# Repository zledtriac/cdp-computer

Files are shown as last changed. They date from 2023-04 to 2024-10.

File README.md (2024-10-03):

# CDP computer
<div align="center">
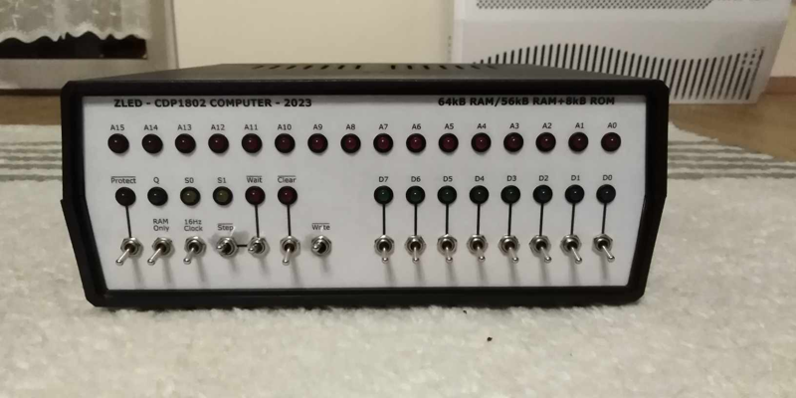
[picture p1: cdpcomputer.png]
  
</div>
This computer is based on the CDP1802 CPU, made for practicing and learning 
electronics and programming. The computer is similar to the COSMAC ELF but I 
designed it from scratch. I tried to fully utilize the features of the CPU and 
I hope I was able to implement enough stuff to demonstrate how an old computer
worked back then.

The fully assembled computer has a frontpanel with switches and two row of LEDs.
The first top row indicates the memory address, and then the next row indicates
the data and the control signals. The switches can be used to input data
in the memory and to control the CPU.

## The motherboard
I made the motherboard to be able to run by itself, so for someone who just want
to do some experiments with an old hardware, it is not necessary to build the 
whole computer. The motherboard contains the CPU, RAM, ROM and the clock 
generator.

### The clock generator
The clock runs on 2.4576MHz so if someone want to make a software Serial 
communcation with the Q and EF pins, 9600 baudrate can be achieved with high 
accuracy.

### The memory
The memory is divided into two sections ROM and RAM, but there is an option to
use only RAM for the program too. This is because EPROMs is a bit difficult to
obtain so for those who are just experimenting, the ROM is not necessary to
make the motherboard running, the RAM is enough. If the J5 pins are shorted the
motherboard will only use the RAM, but if those pins are not shorted then the
first 8192 bytes of RAM will be replaced by the ROM. With this feature the
motherboard can handle 64kB of RAM or 8kB of ROM and 56kB of RAM, depending on 
the state of the J5 pins.

### The DMA interface
The board has a DMA interface which can be used to upload programs or snipets of 
data in the memory while the CPU running, or if it is in the LOAD state.

The DMA interface has an 8bit data input port on the J2 pin header, and it has a 
write control signal on the J3 pin header (pin 2.). if there is a rising edge on 
the write pin, a DMA request will be sent to the CPU and the data pesent on the 
J2 pin header will be written in the memory location addressed by the R0 register 
in the CPU.

## The LED driver board
This board is an extension board, to handle the switches and the indicator LEDs. 
Since the CPU can't drive the LEDs directly, it needs a separate board to have 
the necessary ICs to drive the LEDs with relatively high current (5-6mA).

This board contains D-latches and some logic circuits to extend the 8bit address 
bus to 16bit and to generate a selectable 16Hz clock source and a circuit to be 
able to handle the CLEAR, WAIT, and STEP signals.

## The IO board
This board is made to add some input and output capabilities. The board has 3 
parallel input/output which can be configured from software. It is using the 
dedicated IO cotrol of the CPU so it doesn't need any special controlling routine.

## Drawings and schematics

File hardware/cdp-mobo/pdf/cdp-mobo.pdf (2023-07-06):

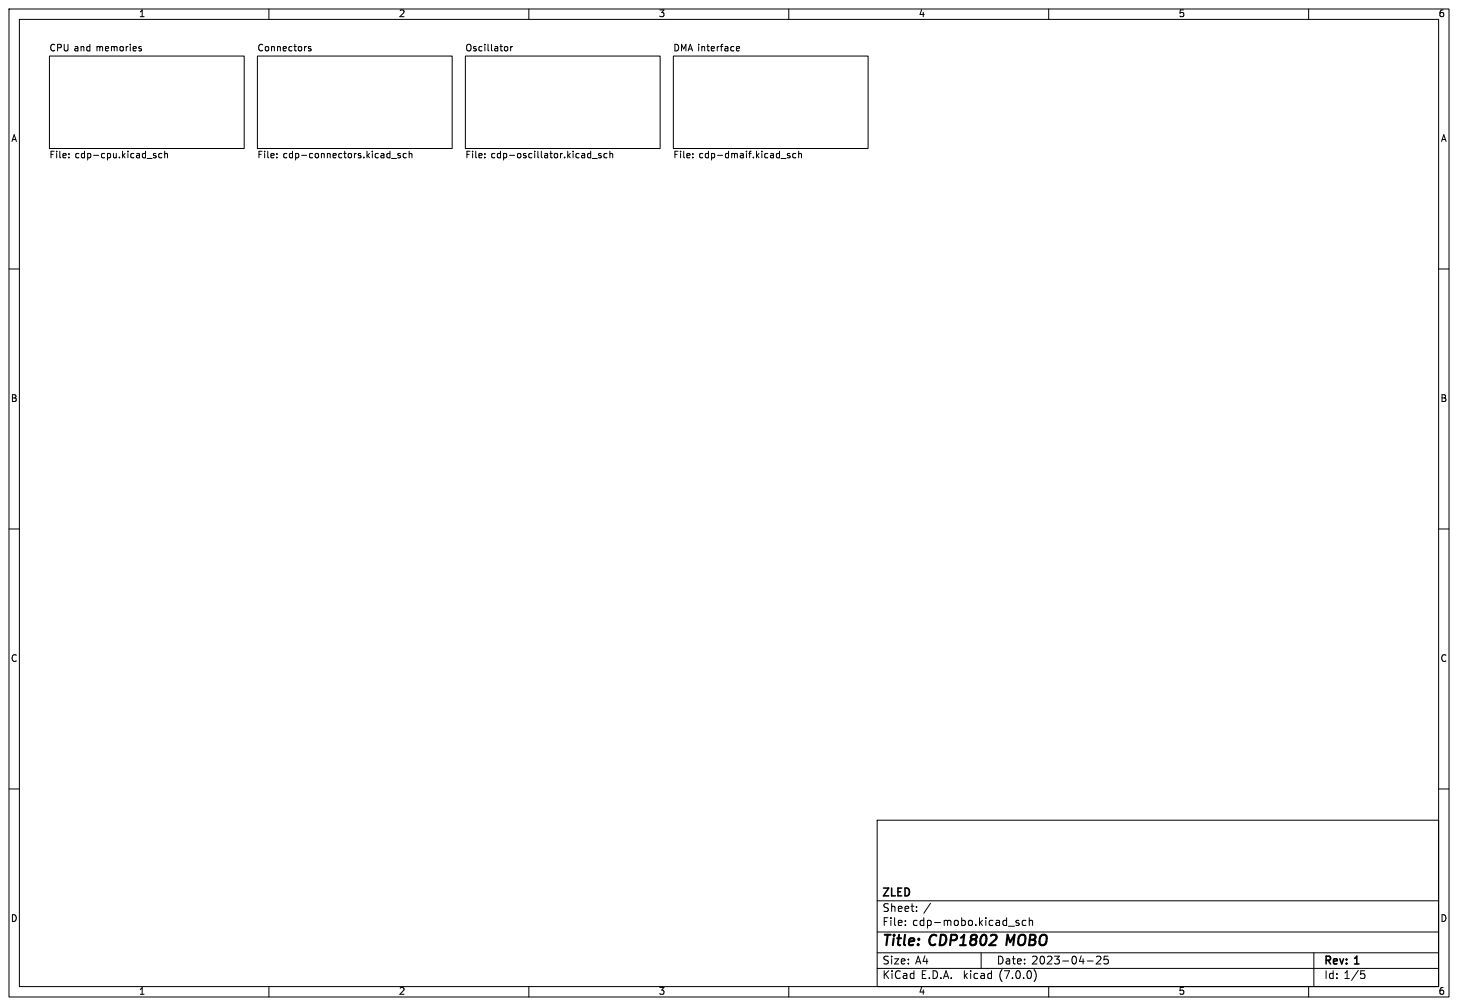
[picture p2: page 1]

File: cdp-mobo.kicad_sch Sheet: / ZLED

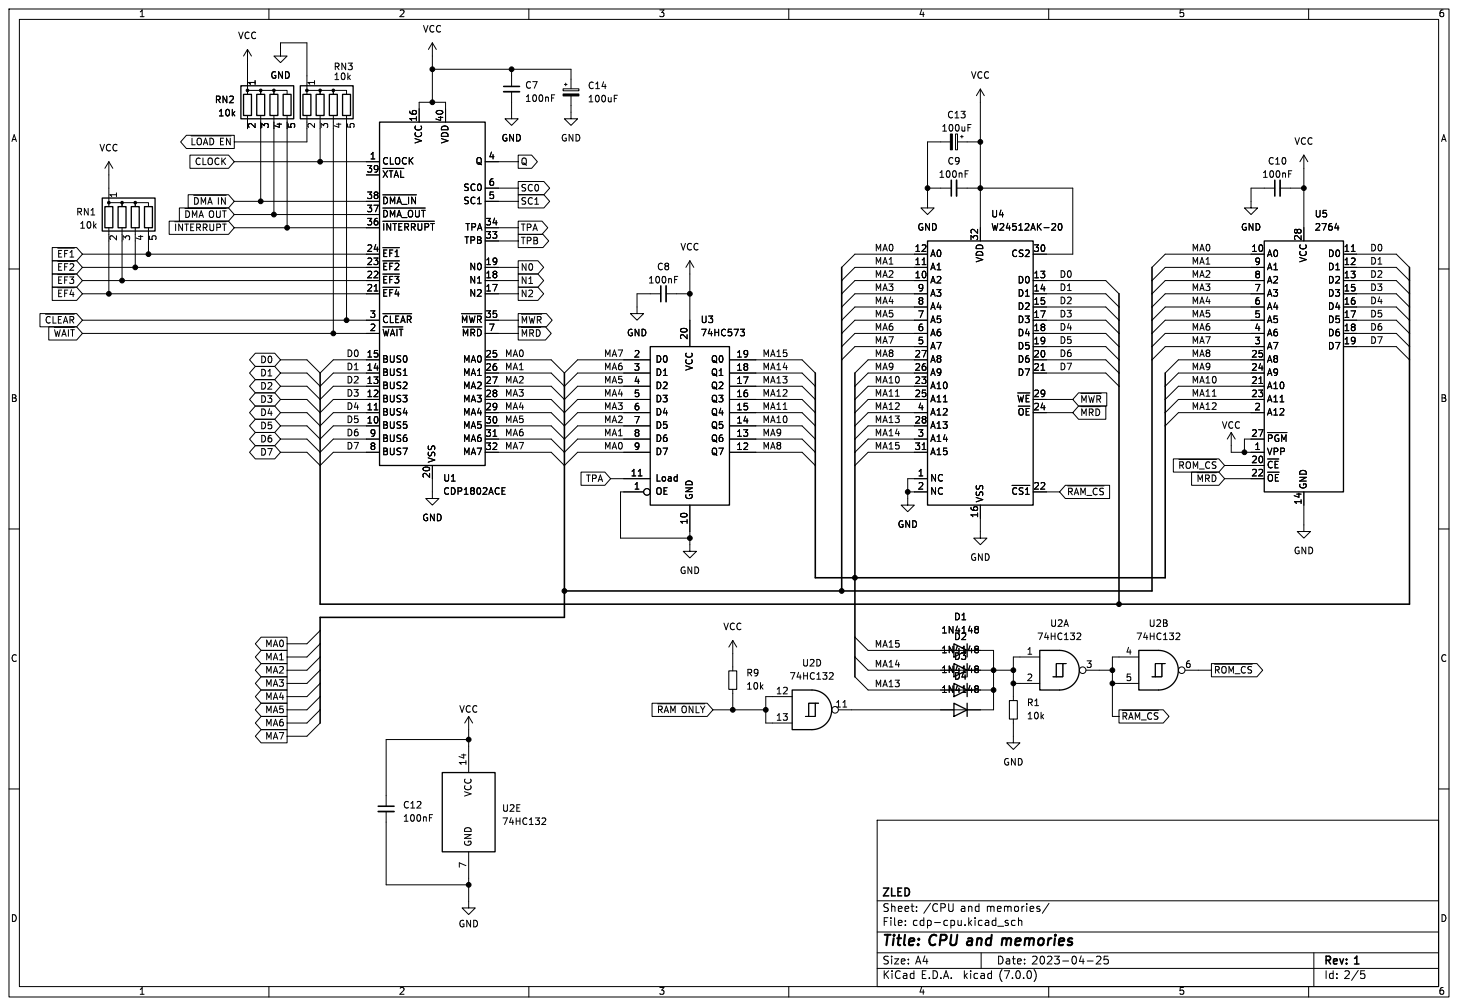
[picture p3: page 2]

Id: 2/5 Title: CPU and memories

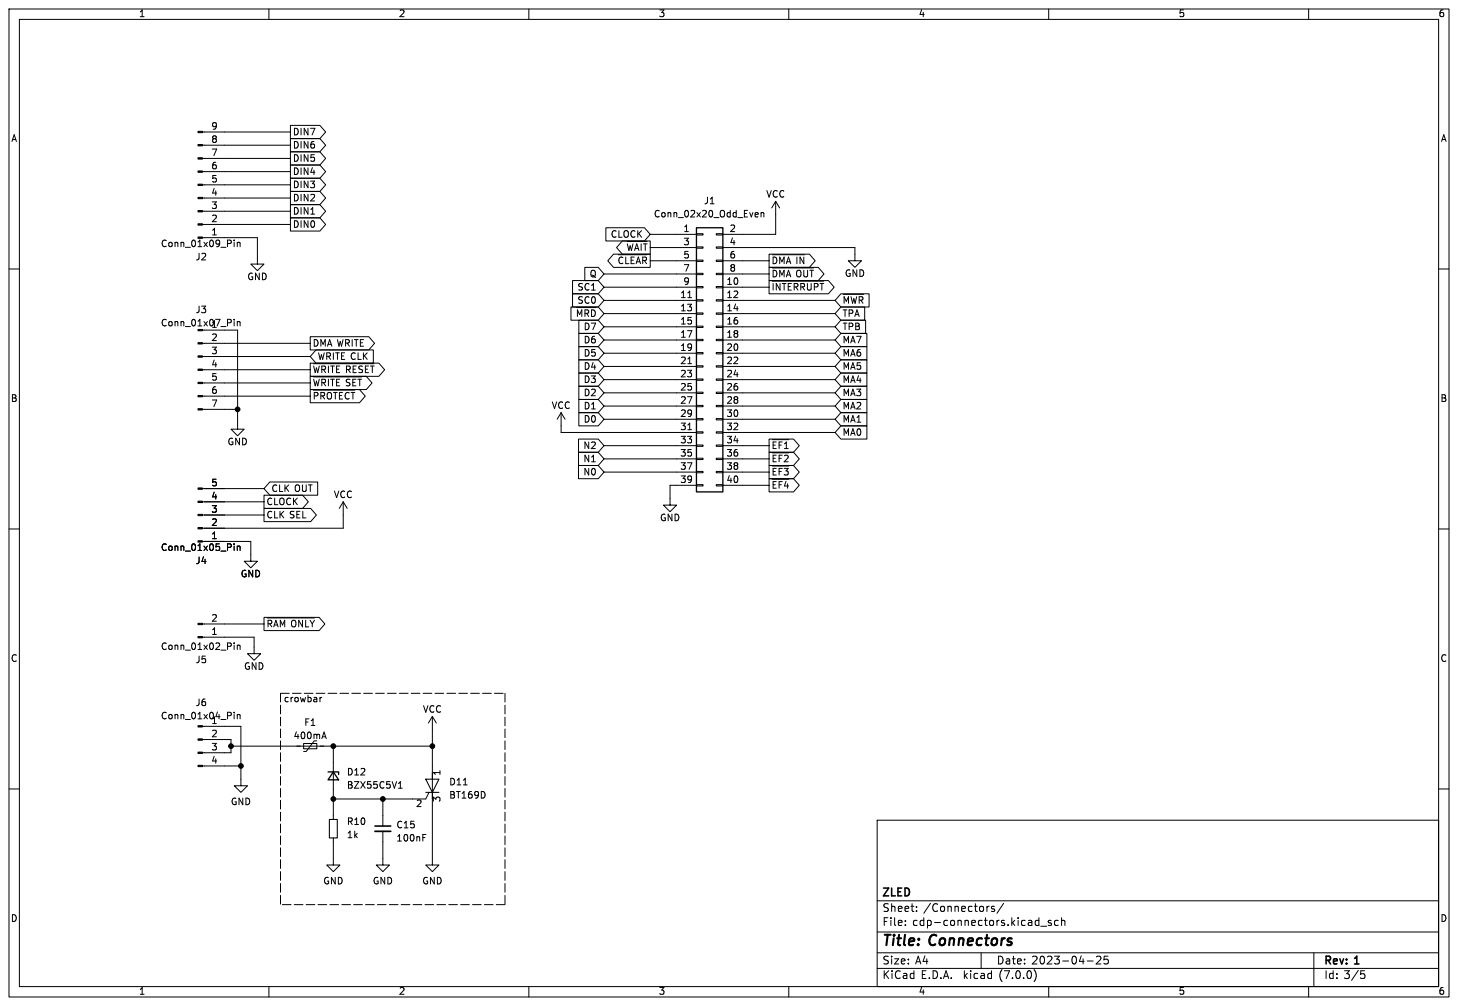
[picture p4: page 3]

File: cdp-connectors.kicad_sch Sheet: /Connectors/ ZLED

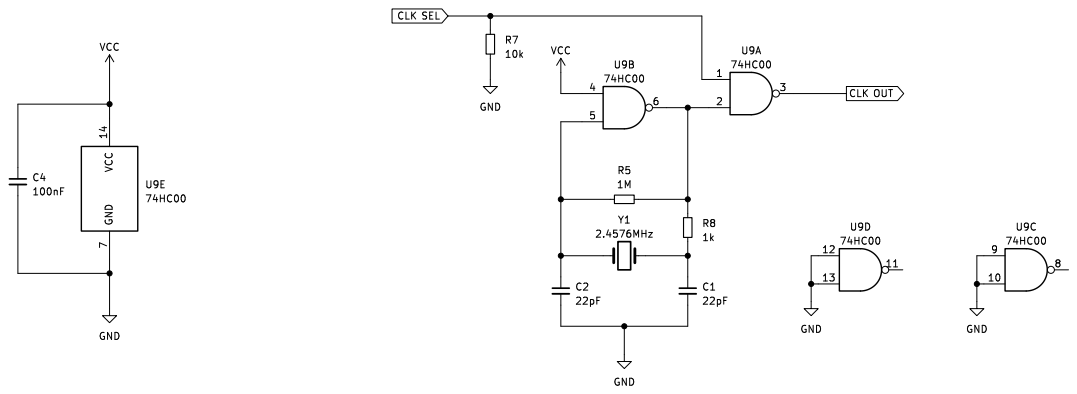
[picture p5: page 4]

Id: 4/5 Title: Oscillator File: cdp-oscillator.kicad_sch Sheet: /Oscillator/ ZLED

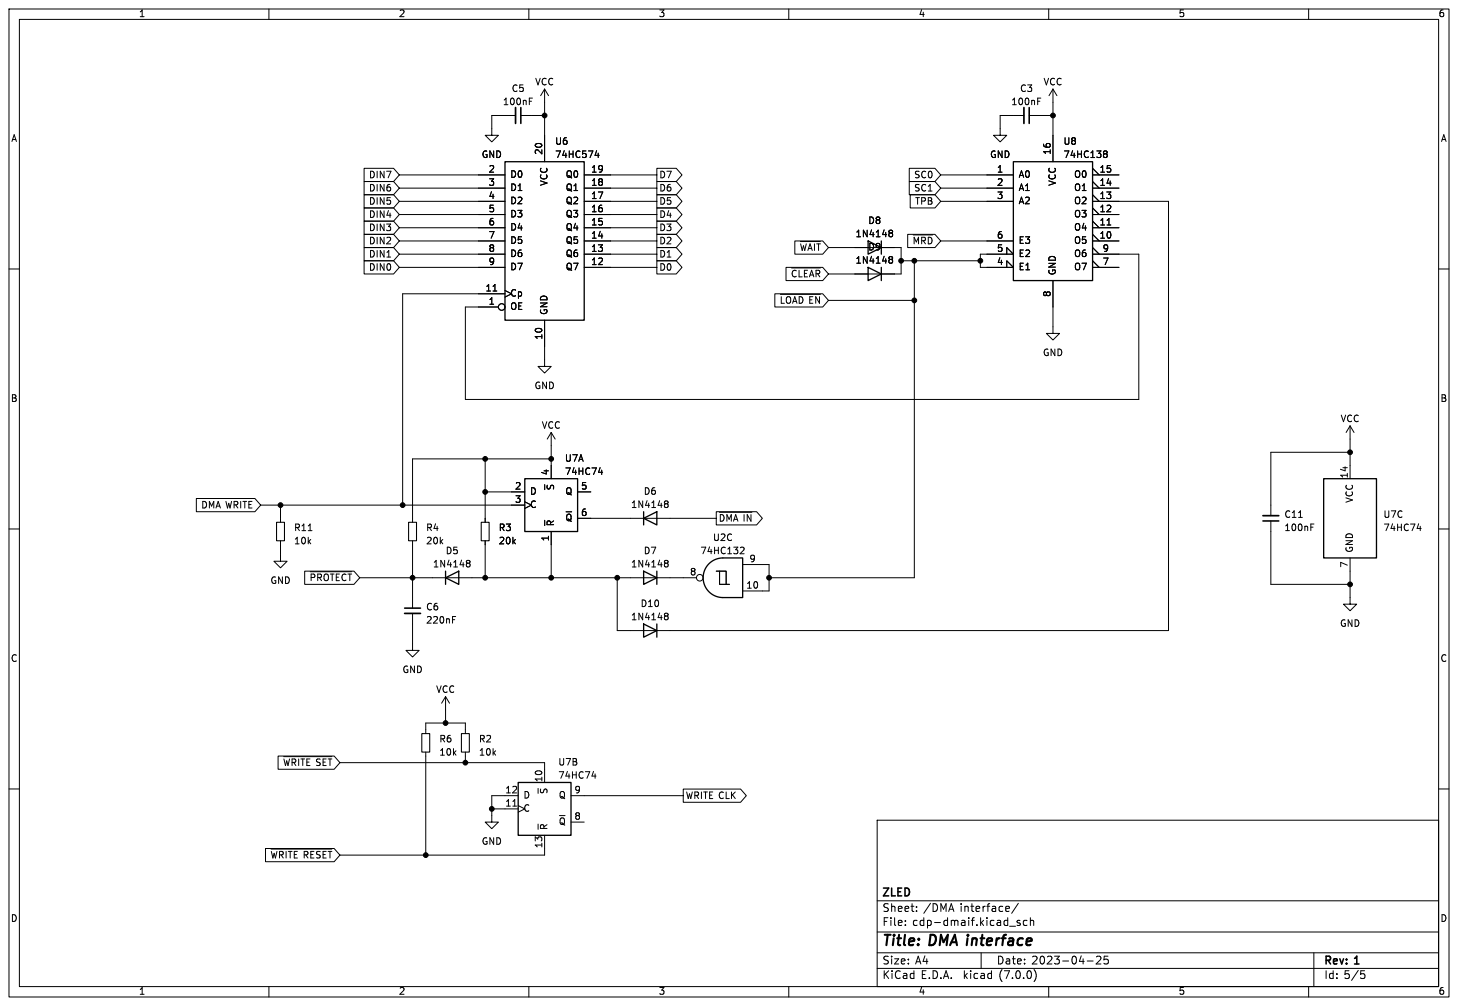
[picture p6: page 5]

File: cdp-dmaif.kicad_sch Sheet: /DMA interface/ ZLED

Id: 5/5 Title: DMA interface

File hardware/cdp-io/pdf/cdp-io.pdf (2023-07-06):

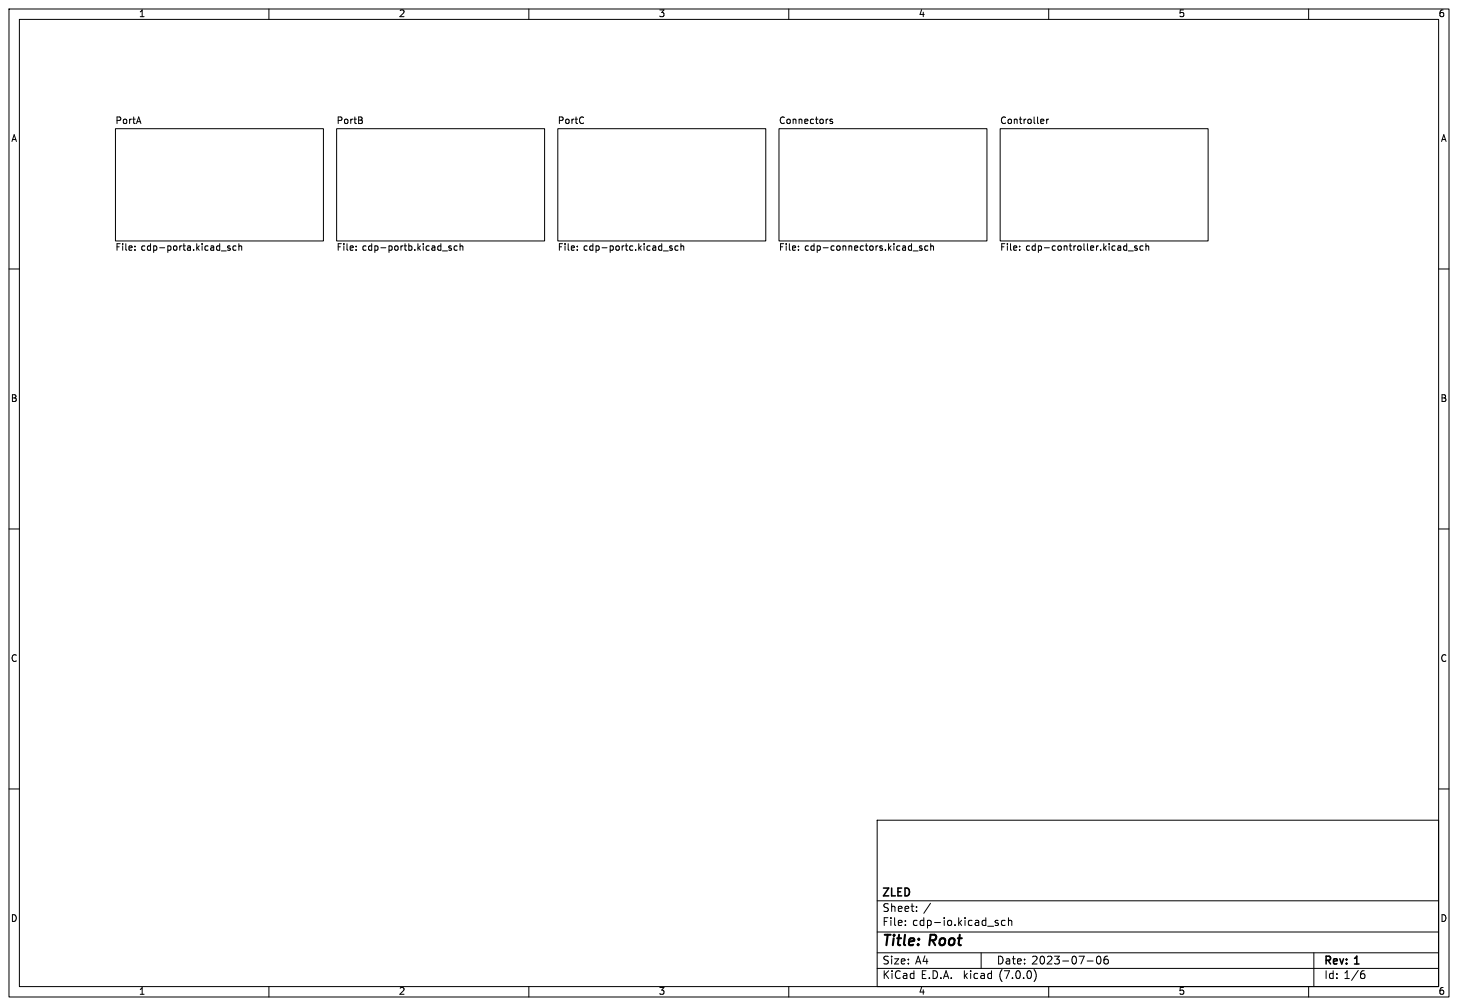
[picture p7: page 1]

File: cdp-portc.kicad_sch PortA

Id: 1/6 Title: Root File: cdp-io.kicad_sch Sheet: / ZLED

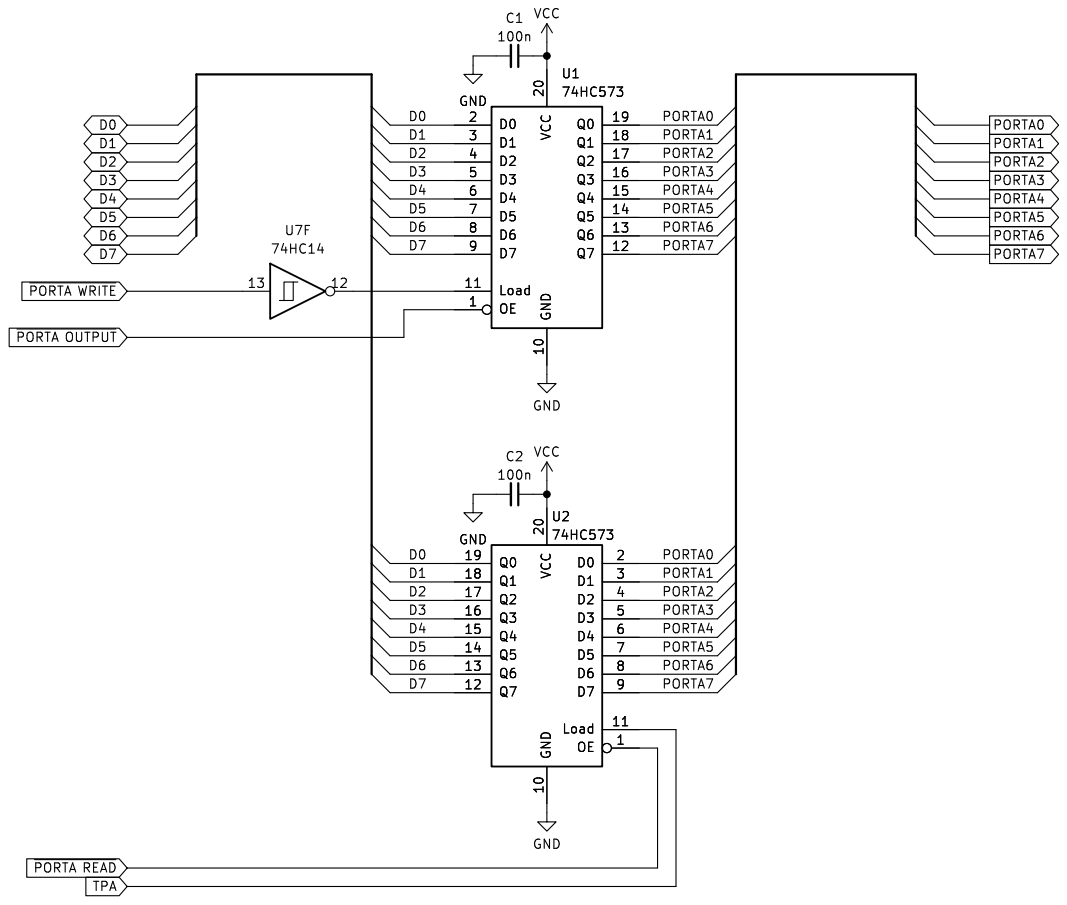
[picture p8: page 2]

File: cdp-porta.kicad_sch Sheet: /PortA/ ZLED

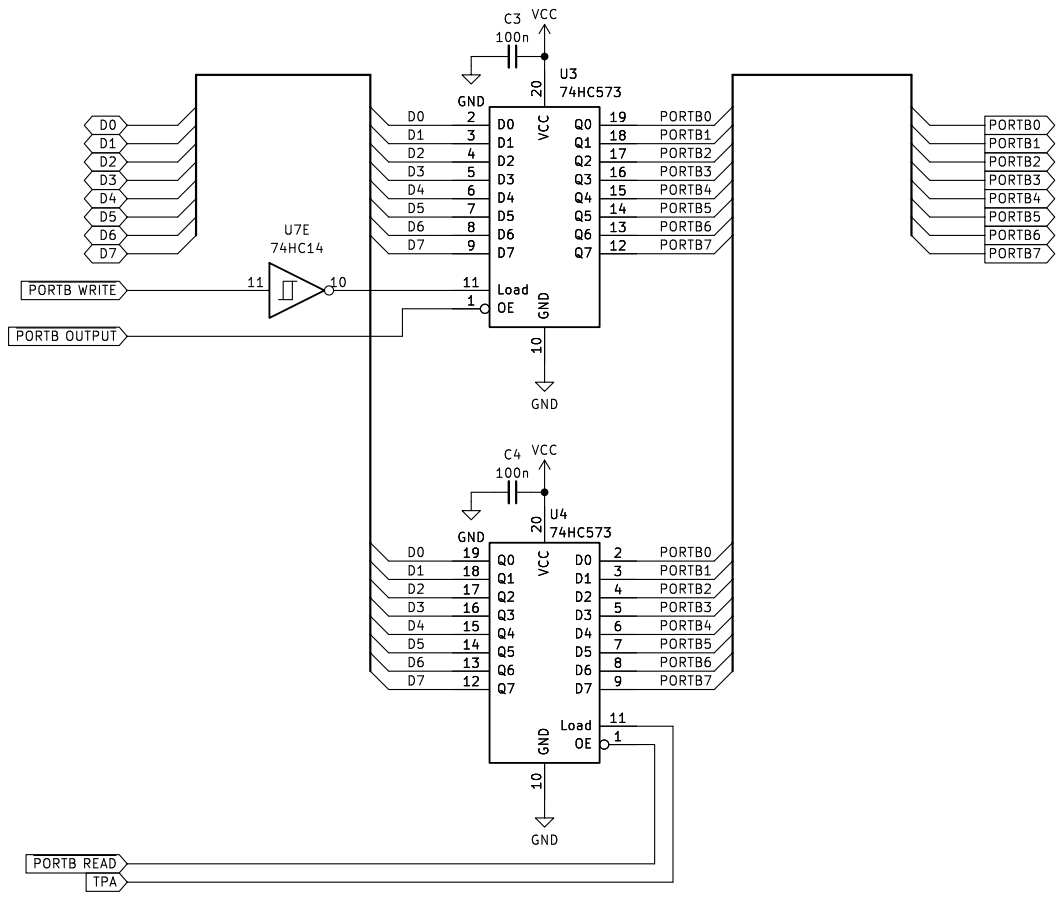
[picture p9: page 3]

File: cdp-portb.kicad_sch Sheet: /PortB/ ZLED

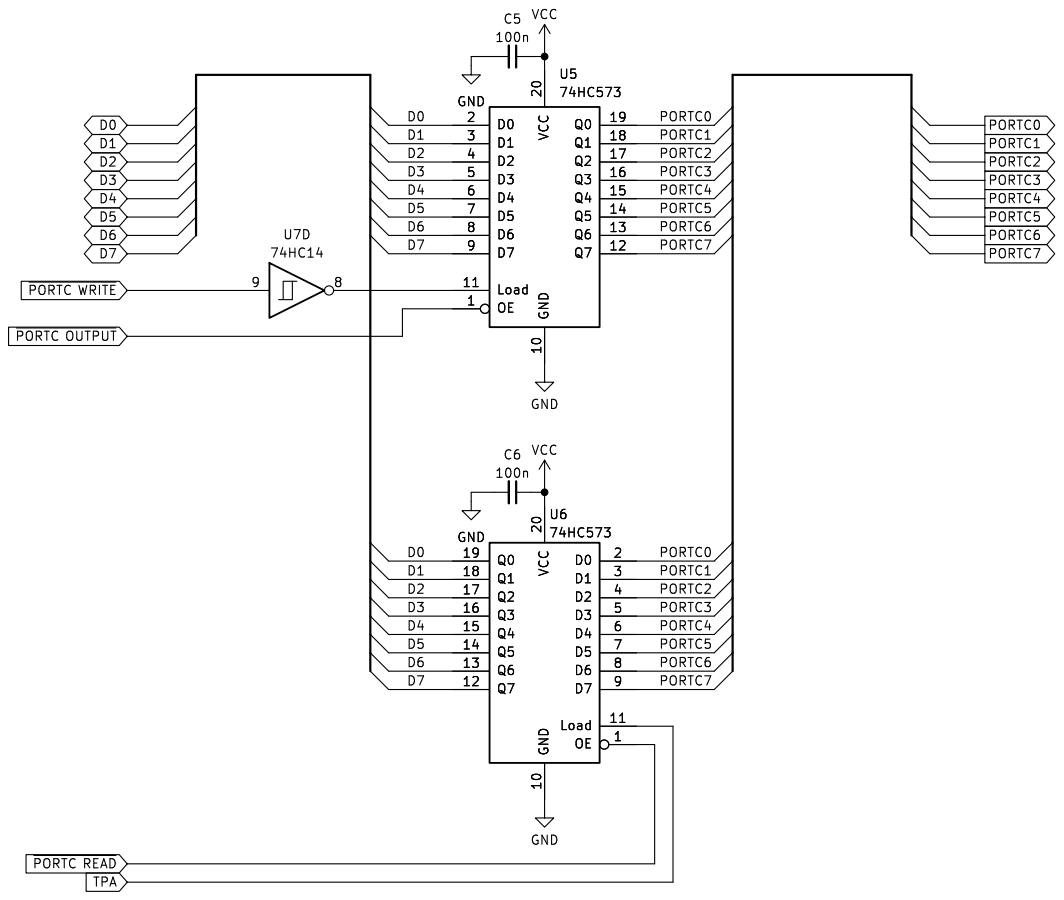
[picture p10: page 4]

File: cdp-portc.kicad_sch Sheet: /PortC/ ZLED

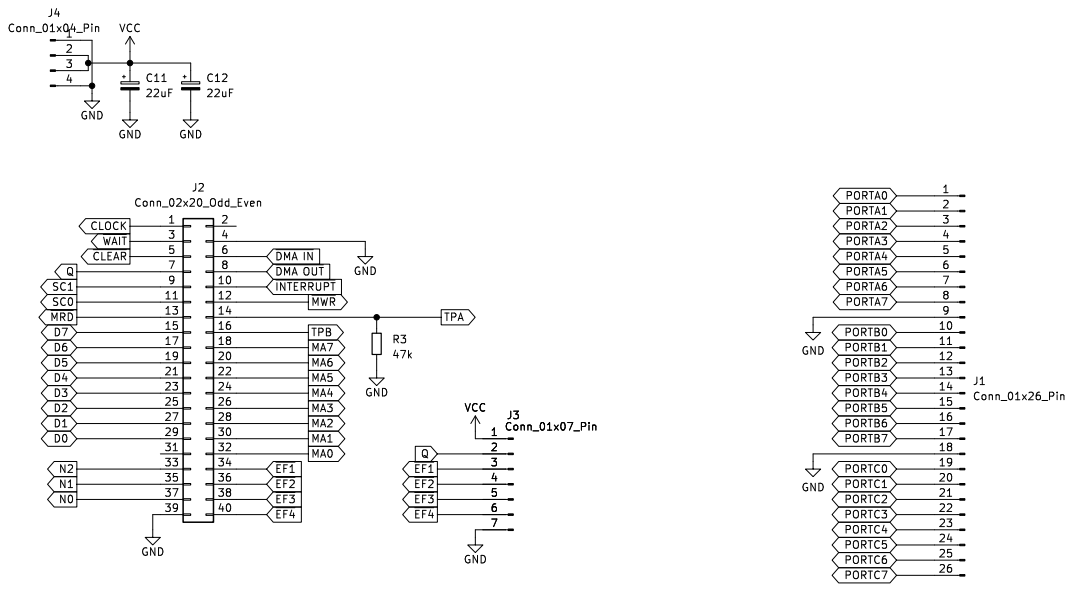
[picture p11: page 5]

J1Conn_01x26_Pin GND GND GND GND

File: cdp-connectors.kicad_sch Sheet: /Connectors/ ZLED

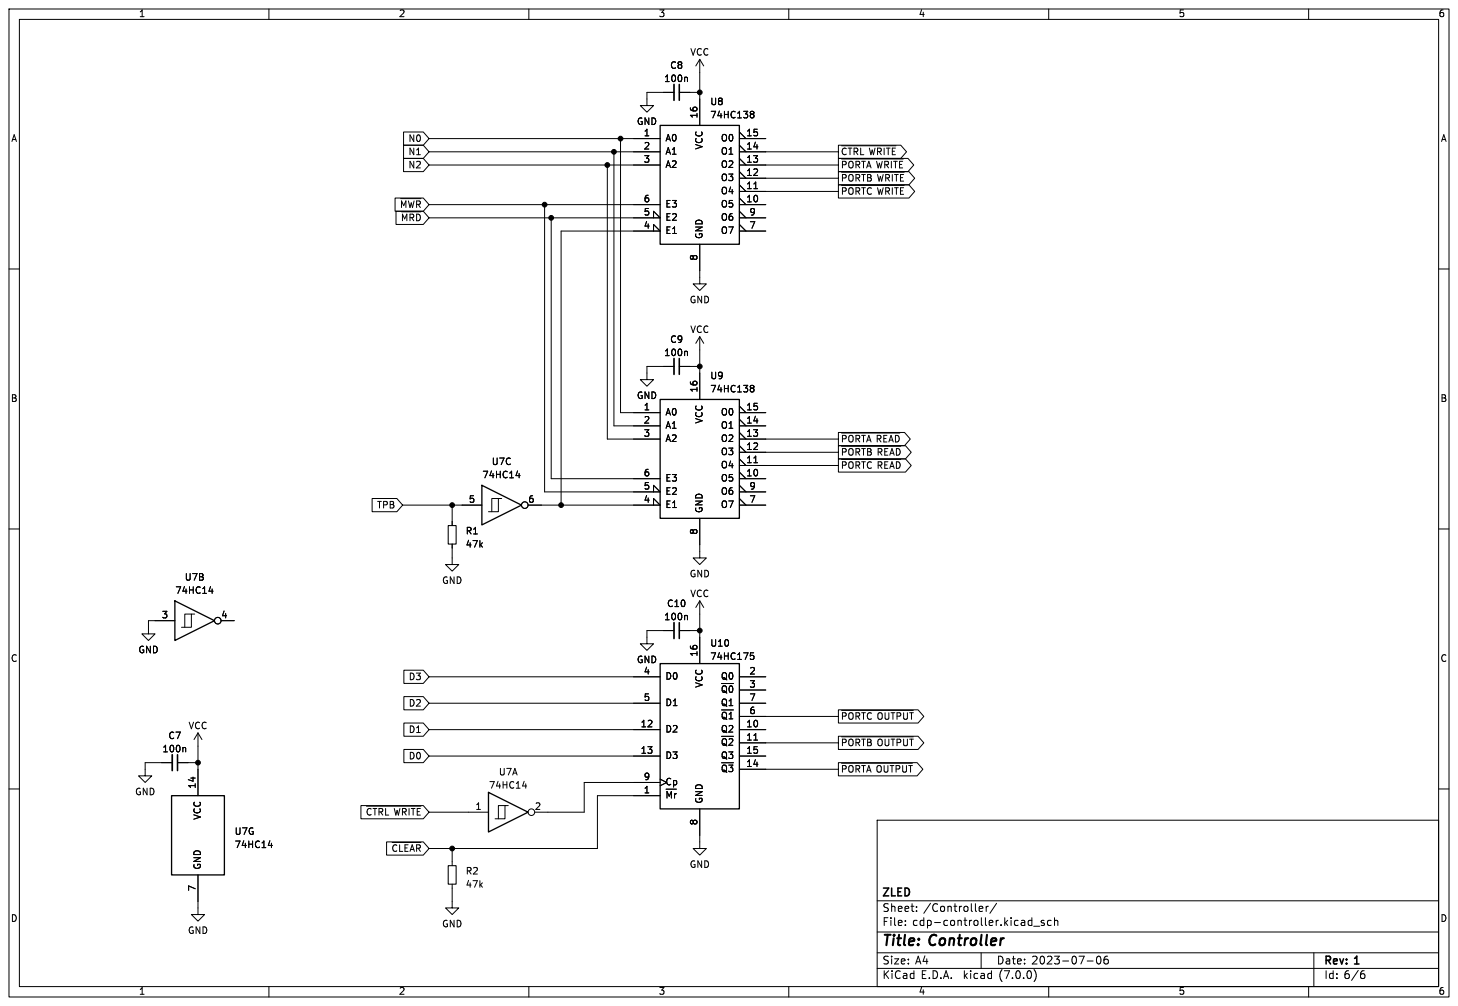
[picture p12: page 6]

Id: 6/6 Title: Controller File: cdp-controller.kicad_sch Sheet: /Controller/ ZLED

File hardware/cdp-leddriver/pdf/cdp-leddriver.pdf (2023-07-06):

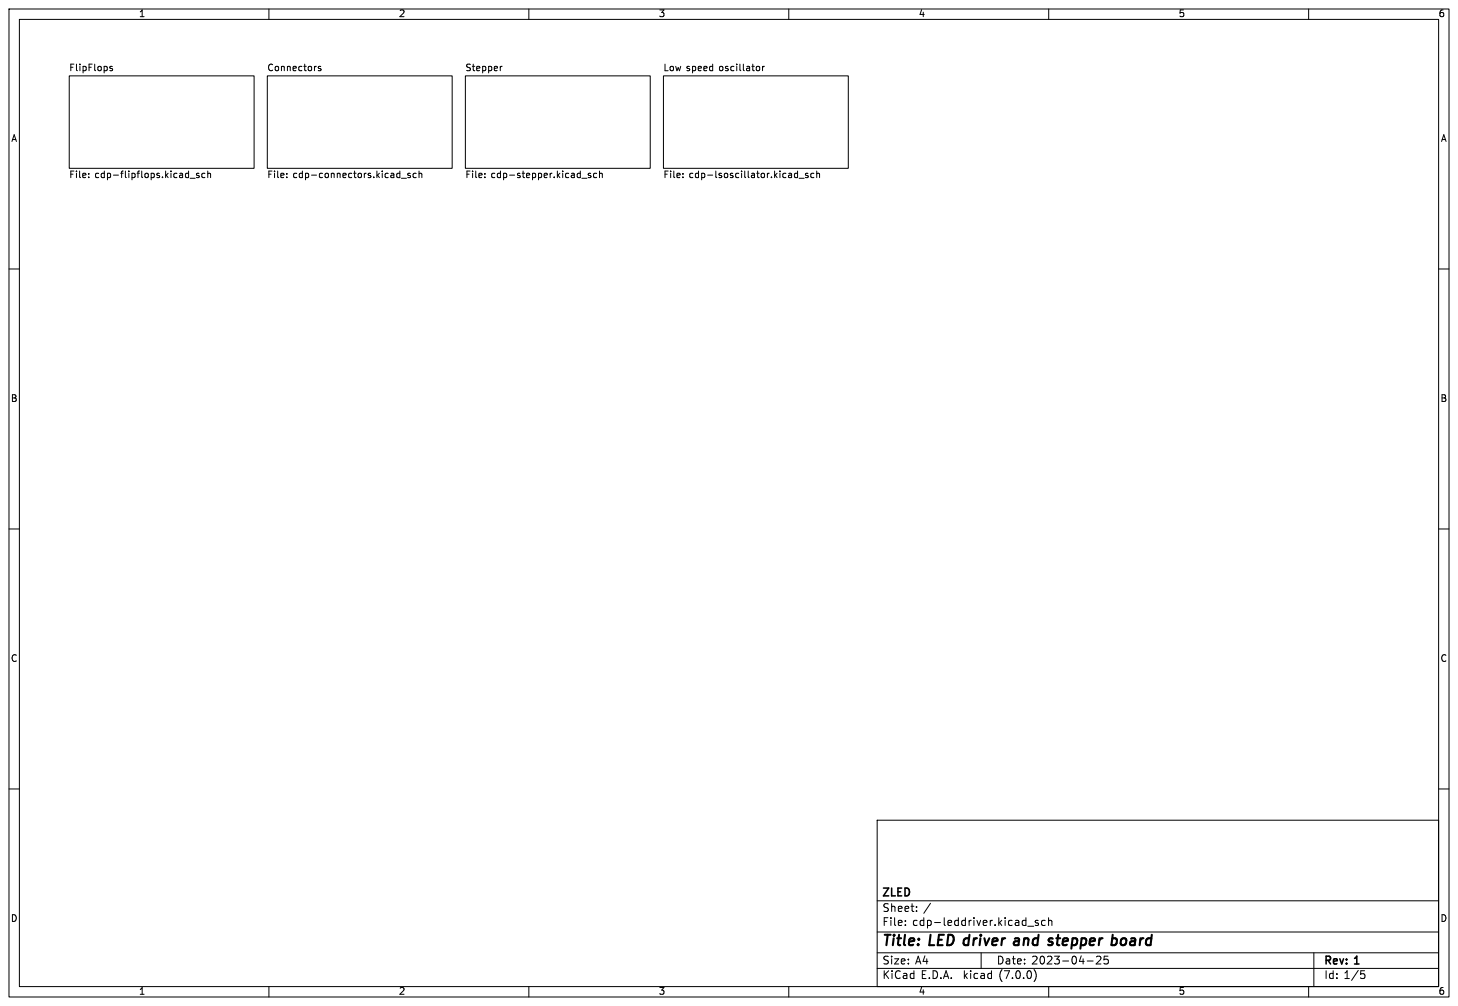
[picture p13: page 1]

FlipFlops File: cdp-flipflops.kicad_sch

Low speed oscillator File: cdp-lsoscillator.kicad_sch Connectors File: cdp-connectors.kicad_sch

Stepper File: cdp-stepper.kicad_sch

File: cdp-leddriver.kicad_sch Sheet: / ZLED

Id: 1/5 Title: LED driver and stepper board


File: cdp-flipflops.kicad_sch Sheet: /FlipFlops/ ZLED

Id: 2/5 Title: Flip-Flops


File: cdp-connectors.kicad_sch Sheet: /Connectors/ ZLED


Id: 4/5 Title: Stepper circuit File: cdp-stepper.kicad_sch Sheet: /Stepper/ ZLED


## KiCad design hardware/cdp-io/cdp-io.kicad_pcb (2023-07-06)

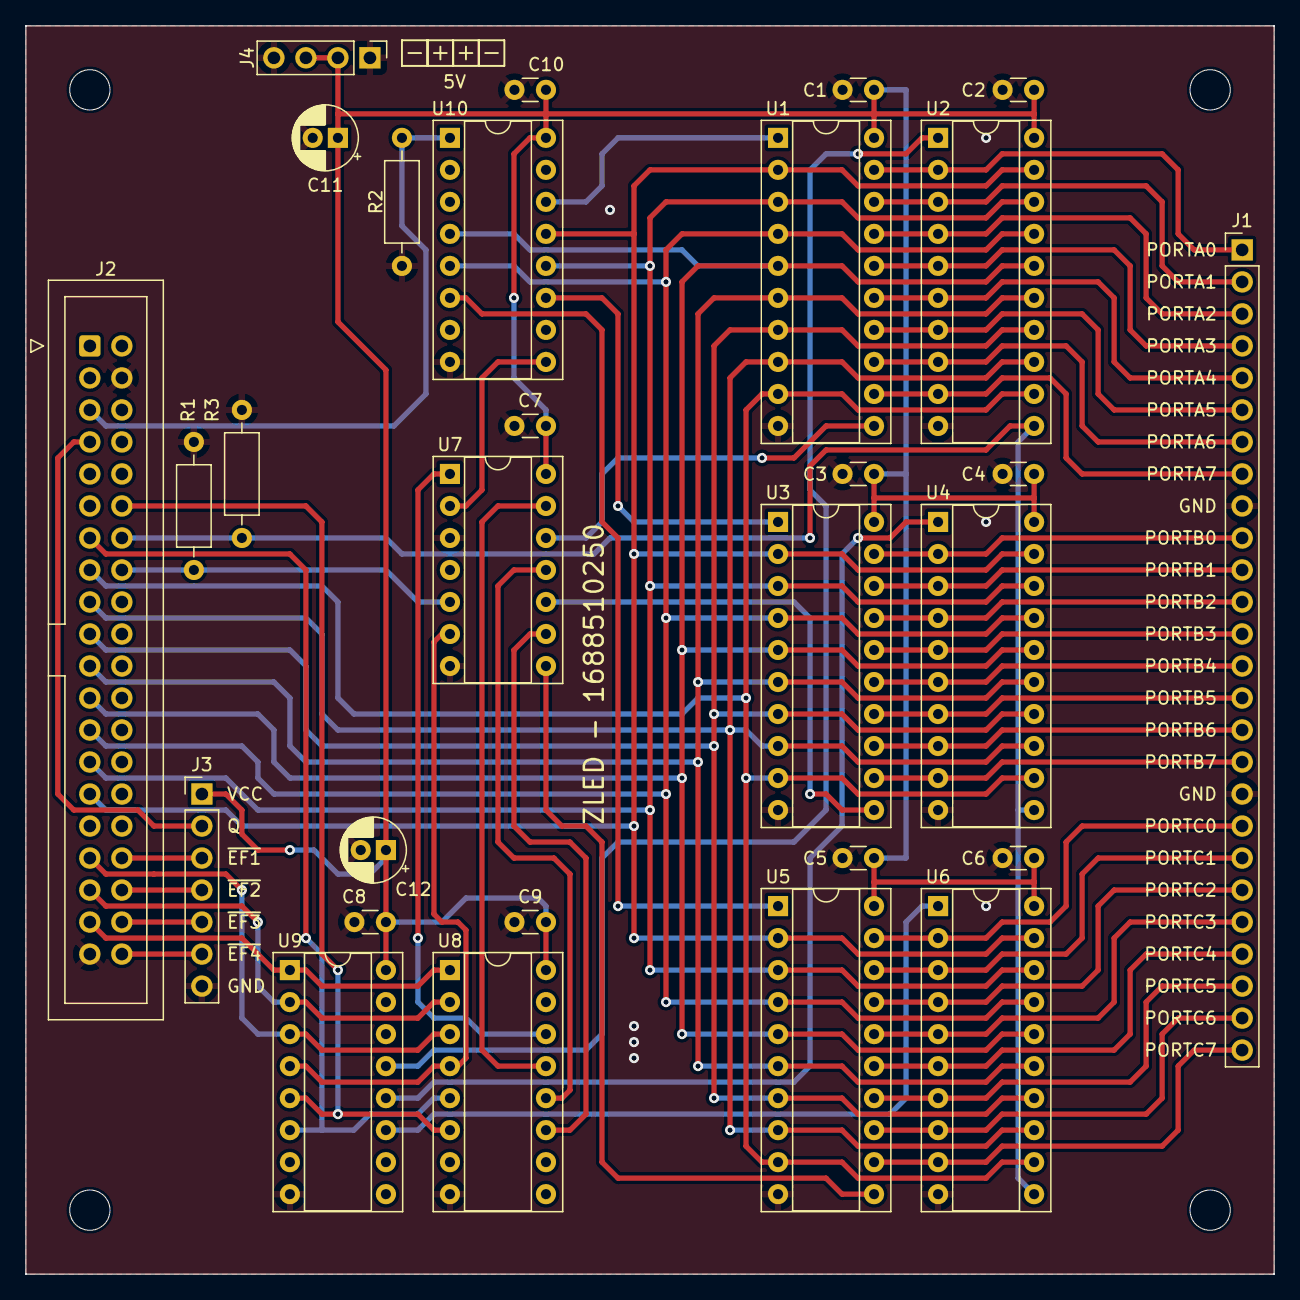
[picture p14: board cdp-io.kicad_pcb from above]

Board: 2 copper layers, 99.1 x 99.1 mm, 29 parts (0 on the bottom side), 62 nets.

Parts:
C1, C2, C3, C4, C5, C6, C7, C8, C9, C10: 100n; C_Disc_D3.0mm_W1.6mm_P2.50mm
C11, C12: 22uF; CP_Radial_D5.0mm_P2.00mm
J1: Conn_01x26_Pin; PinHeader_1x26_P2.54mm_Vertical
J2: Conn_02x20_Odd_Even; IDC-Header_2x20_P2.54mm_Vertical
J3: Conn_01x07_Pin; PinHeader_1x07_P2.54mm_Vertical
J4: Conn_01x04_Pin; PinHeader_1x04_P2.54mm_Vertical
R1, R2, R3: 47k; R_Axial_DIN0207_L6.3mm_D2.5mm_P10.16mm_Horizontal
U1, U2, U3, U4, U5, U6: 74HC573; DIP-20_W7.62mm_Socket
U7: 74HC14; DIP-14_W7.62mm_Socket
U8, U9: 74HC138; DIP-16_W7.62mm_Socket
U10: 74HC175; DIP-16_W7.62mm_Socket

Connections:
D0: J2.29, U1.2 (D0), U2.19 (Q0), U3.2 (D0), U4.19 (Q0), U5.2 (D0), U6.19 (Q0), U10.13 (D3)
D1: J2.27, U1.3 (D1), U2.18 (Q1), U3.3 (D1), U4.18 (Q1), U5.3 (D1), U6.18 (Q1), U10.12 (D2)
D2: J2.25, U1.4 (D2), U2.17 (Q2), U3.4 (D2), U4.17 (Q2), U5.4 (D2), U6.17 (Q2), U10.5 (D1)
D3: J2.23, U1.5 (D3), U2.16 (Q3), U3.5 (D3), U4.16 (Q3), U5.5 (D3), U6.16 (Q3), U10.4 (D0)
D4: J2.21, U1.6 (D4), U2.15 (Q4), U3.6 (D4), U4.15 (Q4), U5.6 (D4), U6.15 (Q4)
D5: J2.19, U1.7 (D5), U2.14 (Q5), U3.7 (D5), U4.14 (Q5), U5.7 (D5), U6.14 (Q5)
D6: J2.17, U1.8 (D6), U2.13 (Q6), U3.8 (D6), U4.13 (Q6), U5.8 (D6), U6.13 (Q6)
D7: J2.15, U1.9 (D7), U2.12 (Q7), U3.9 (D7), U4.12 (Q7), U5.9 (D7), U6.12 (Q7)
GND: C1.2, C2.2, C3.2, C4.2, C5.2, C6.2, C7.2, C8.2, C9.2, C10.2, C11.2, C12.2, J1.9, J1.18, J2.4, J2.39, J3.7, J4.1, J4.4, R1.2, R2.2, R3.2, U1.10 (GND), U2.10 (GND), U3.10 (GND), U4.10 (GND), U5.10 (GND), U6.10 (GND), U7.3, U7.7 (GND), U8.8 (GND), U9.8 (GND), U10.8 (GND)
N0: J2.37, U8.1 (A0), U9.1 (A0)
N1: J2.35, U8.2 (A1), U9.2 (A1)
N2: J2.33, U8.3 (A2), U9.3 (A2)
unnamed: U1.11 (Load), U7.12
unnamed: U3.11 (Load), U7.10
unnamed: U5.11 (Load), U7.8
unnamed: U7.6, U8.4 (E1), U9.4 (E1)
unnamed: U7.2, U10.9 (Cp)
PORTA0: J1.1, U1.19 (Q0), U2.2 (D0)
PORTA1: J1.2, U1.18 (Q1), U2.3 (D1)
PORTA2: J1.3, U1.17 (Q2), U2.4 (D2)
PORTA3: J1.4, U1.16 (Q3), U2.5 (D3)
PORTA4: J1.5, U1.15 (Q4), U2.6 (D4)
PORTA5: J1.6, U1.14 (Q5), U2.7 (D5)
PORTA6: J1.7, U1.13 (Q6), U2.8 (D6)
PORTA7: J1.8, U1.12 (Q7), U2.9 (D7)
PORTB0: J1.10, U3.19 (Q0), U4.2 (D0)
PORTB1: J1.11, U3.18 (Q1), U4.3 (D1)
PORTB2: J1.12, U3.17 (Q2), U4.4 (D2)
PORTB3: J1.13, U3.16 (Q3), U4.5 (D3)
PORTB4: J1.14, U3.15 (Q4), U4.6 (D4)
PORTB5: J1.15, U3.14 (Q5), U4.7 (D5)
PORTB6: J1.16, U3.13 (Q6), U4.8 (D6)
PORTB7: J1.17, U3.12 (Q7), U4.9 (D7)
PORTC0: J1.19, U5.19 (Q0), U6.2 (D0)
PORTC1: J1.20, U5.18 (Q1), U6.3 (D1)
PORTC2: J1.21, U5.17 (Q2), U6.4 (D2)
PORTC3: J1.22, U5.16 (Q3), U6.5 (D3)
PORTC4: J1.23, U5.15 (Q4), U6.6 (D4)
PORTC5: J1.24, U5.14 (Q5), U6.7 (D5)
PORTC6: J1.25, U5.13 (Q6), U6.8 (D6)
PORTC7: J1.26, U5.12 (Q7), U6.9 (D7)
Q: J2.7, J3.2
TPA: J2.14, R3.1, U2.11 (Load), U4.11 (Load), U6.11 (Load)
TPB: J2.16, R1.1, U7.5
VCC: C1.1, C2.1, C3.1, C4.1, C5.1, C6.1, C7.1, C8.1, C9.1, C10.1, C11.1, C12.1, J3.1, J4.2, J4.3, U1.20 (VCC), U2.20 (VCC), U3.20 (VCC), U4.20 (VCC), U5.20 (VCC), U6.20 (VCC), U7.14 (VCC), U8.16 (VCC), U9.16 (VCC), U10.16 (VCC)
~CLEAR: J2.5, R2.1, U10.1 (~Mr)
~CTRL WRITE: U7.1, U8.14 (O1)
~EF1: J2.34, J3.3
~EF2: J2.36, J3.4
~EF3: J2.38, J3.5
~EF4: J2.40, J3.6
~MRD: J2.13, U8.5 (E2), U9.6 (E3)
~MWR: J2.12, U8.6 (E3), U9.5 (E2)
~PORTA OUTPUT: U1.1 (OE), U10.14 (~Q3)
~PORTA READ: U2.1 (OE), U9.13 (O2)
~PORTA WRITE: U7.13, U8.13 (O2)
~PORTB OUTPUT: U3.1 (OE), U10.11 (~Q2)
~PORTB READ: U4.1 (OE), U9.12 (O3)
~PORTB WRITE: U7.11, U8.12 (O3)
~PORTC OUTPUT: U5.1 (OE), U10.6 (~Q1)
~PORTC READ: U6.1 (OE), U9.11 (O4)
~PORTC WRITE: U7.9, U8.11 (O4)

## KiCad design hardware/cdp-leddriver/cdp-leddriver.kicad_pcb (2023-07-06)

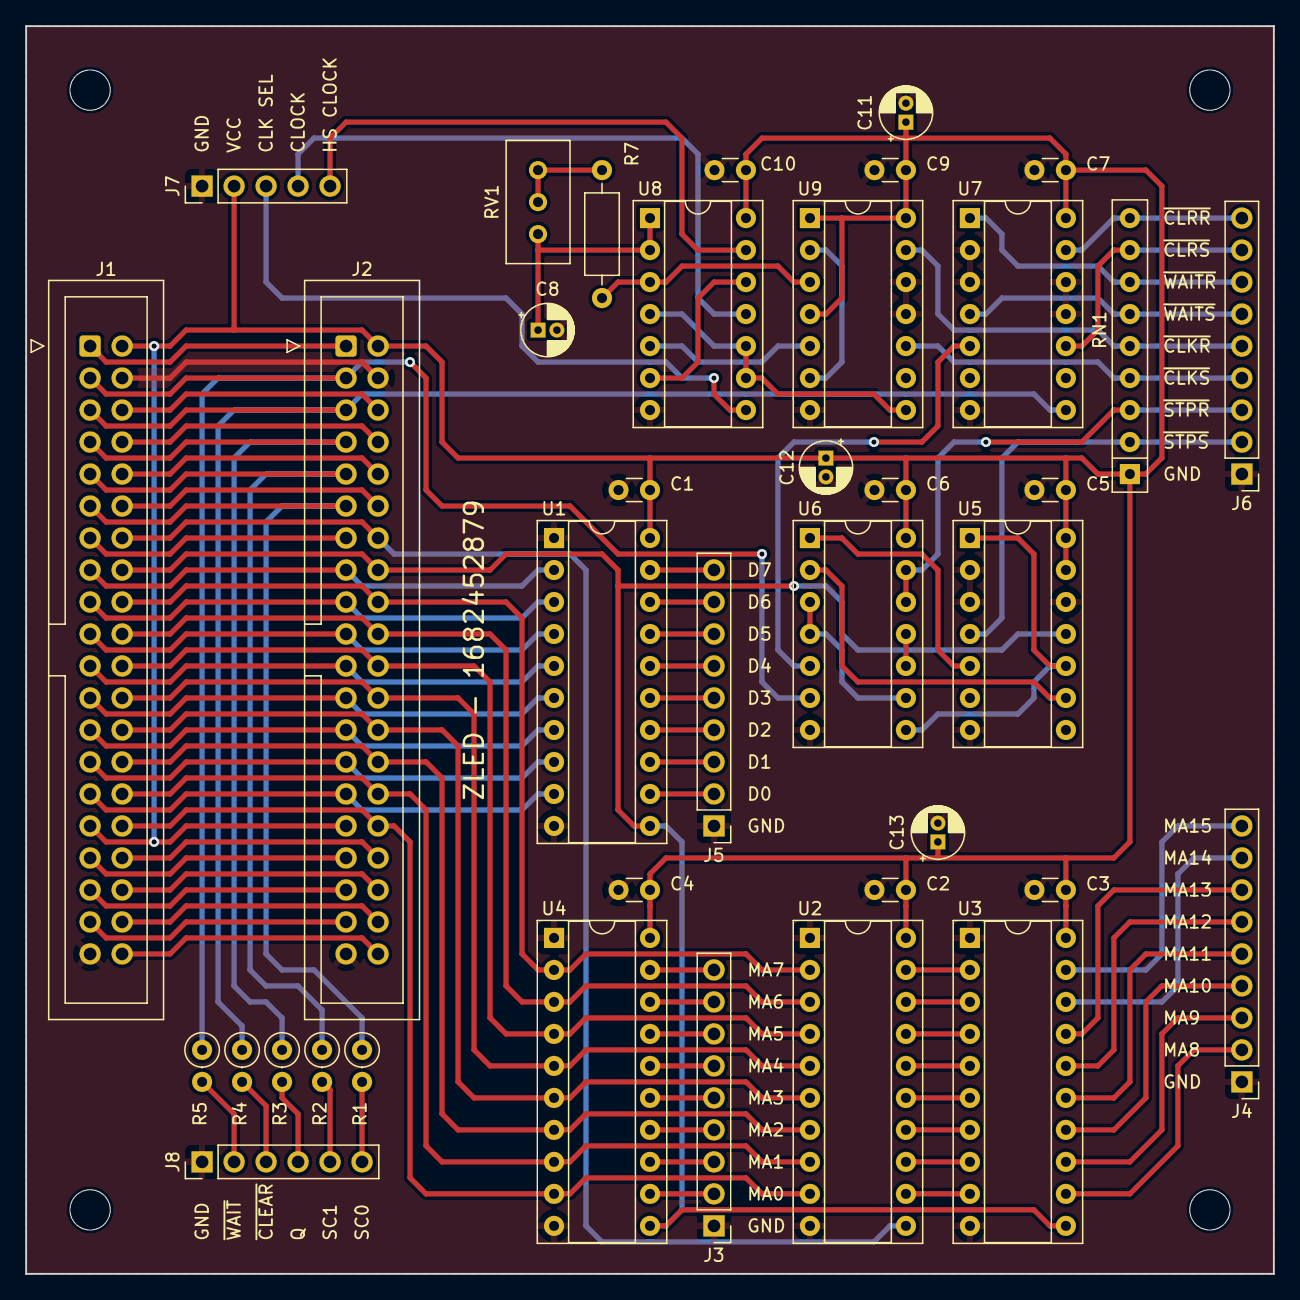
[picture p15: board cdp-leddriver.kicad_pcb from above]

Board: 2 copper layers, 99.1 x 99.1 mm, 38 parts (0 on the bottom side), 99 nets.

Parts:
C1, C2, C3, C4, C5, C6, C7, C9, C10: 100nF; C_Disc_D3.0mm_W1.6mm_P2.50mm
C8: 1uF; CP_Radial_D4.0mm_P1.50mm
C11, C12, C13: 22uF; CP_Radial_D4.0mm_P1.50mm
J1, J2: Conn_02x20_Odd_Even; IDC-Header_2x20_P2.54mm_Vertical
J3, J4, J5, J6: Conn_01x09_Pin; PinHeader_1x09_P2.54mm_Vertical
J7: Conn_01x05_Pin; PinHeader_1x05_P2.54mm_Vertical
J8: Conn_01x06_Pin; PinHeader_1x06_P2.54mm_Vertical
R1, R2, R3, R4, R5: 1k; R_Axial_DIN0207_L6.3mm_D2.5mm_P2.54mm_Vertical
R7: 4k7; R_Axial_DIN0207_L6.3mm_D2.5mm_P10.16mm_Horizontal
RN1: 10k; R_Array_SIP9
RV1: 10k; Potentiometer_Bourns_3296W_Vertical
U1, U3, U4: 74HC574; DIP-20_W7.62mm_Socket
U2: 74HC573; DIP-20_W7.62mm_Socket
U5, U7, U9: 74HC74; DIP-14_W7.62mm_Socket
U6, U8: 74HC132; DIP-14_W7.62mm_Socket

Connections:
AOUT0: J3.2, U4.12 (Q7)
AOUT1: J3.3, U4.13 (Q6)
AOUT2: J3.4, U4.14 (Q5)
AOUT3: J3.5, U4.15 (Q4)
AOUT4: J3.6, U4.16 (Q3)
AOUT5: J3.7, U4.17 (Q2)
AOUT6: J3.8, U4.18 (Q1)
AOUT7: J3.9, U4.19 (Q0)
AOUT8: J4.2, U3.12 (Q7)
AOUT9: J4.3, U3.13 (Q6)
AOUT10: J4.4, U3.14 (Q5)
AOUT11: J4.5, U3.15 (Q4)
AOUT12: J4.6, U3.16 (Q3)
AOUT13: J4.7, U3.17 (Q2)
AOUT14: J4.8, U3.18 (Q1)
AOUT15: J4.9, U3.19 (Q0)
CLK OUT: J7.4, U8.11
CLK SEL: J7.3, U8.8
CLOCK: J1.1, J2.1
D0: J1.29, J2.29, U1.9 (D7)
D1: J1.27, J2.27, U1.8 (D6)
D2: J1.25, J2.25, U1.7 (D5)
D3: J1.23, J2.23, U1.6 (D4)
D4: J1.21, J2.21, U1.5 (D3)
D5: J1.19, J2.19, U1.4 (D2)
D6: J1.17, J2.17, U1.3 (D1)
D7: J1.15, J2.15, U1.2 (D0)
DOUT0: J5.2, U1.12 (Q7)
DOUT1: J5.3, U1.13 (Q6)
DOUT2: J5.4, U1.14 (Q5)
DOUT3: J5.5, U1.15 (Q4)
DOUT4: J5.6, U1.16 (Q3)
DOUT5: J5.7, U1.17 (Q2)
DOUT6: J5.8, U1.18 (Q1)
DOUT7: J5.9, U1.19 (Q0)
GND: C1.2, C2.2, C3.2, C4.2, C5.2, C6.2, C7.2, C8.2, C9.2, C10.2, C11.2, C12.2, C13.2, J1.4, J1.39, J2.4, J2.39, J3.1, J4.1, J5.1, J6.1, J7.1, J8.1, U1.1 (OE), U1.10 (GND), U2.1 (OE), U2.10 (GND), U3.1 (OE), U3.10 (GND), U4.1 (OE), U4.10 (GND), U5.2 (D), U5.3 (C), U5.7 (GND), U5.12 (D), U6.7 (GND), U7.2 (D), U7.3 (C), U7.7 (GND), U7.11 (C), U7.12 (D), U8.7 (GND), U9.7 (GND), U9.11 (C), U9.12 (D)
HS CLK: J7.5, U8.13
MA0: J1.32, J2.32, U2.9 (D7), U4.9 (D7)
MA1: J1.30, J2.30, U2.8 (D6), U4.8 (D6)
MA2: J1.28, J2.28, U2.7 (D5), U4.7 (D5)
MA3: J1.26, J2.26, U2.6 (D4), U4.6 (D4)
MA4: J1.24, J2.24, U2.5 (D3), U4.5 (D3)
MA5: J1.22, J2.22, U2.4 (D2), U4.4 (D2)
MA6: J1.20, J2.20, U2.3 (D1), U4.3 (D1)
MA7: J1.18, J2.18, U2.2 (D0), U4.2 (D0)
N0: J1.37, J2.37
N1: J1.35, J2.35
N2: J1.33, J2.33
unnamed: C8.1, RV1.3, U8.1, U8.2
unnamed: J8.2, R5.2
unnamed: J8.3, R4.2
unnamed: J8.4, R3.2
unnamed: J8.5, R2.2
unnamed: J8.6, R1.2
unnamed: R7.1, RV1.1, RV1.2
unnamed: U2.19 (Q0), U3.2 (D0)
unnamed: U2.18 (Q1), U3.3 (D1)
unnamed: U2.17 (Q2), U3.4 (D2)
unnamed: U2.16 (Q3), U3.5 (D3)
unnamed: U2.15 (Q4), U3.6 (D4)
unnamed: U2.14 (Q5), U3.7 (D5)
unnamed: U2.13 (Q6), U3.8 (D6)
unnamed: U2.12 (Q7), U3.9 (D7)
unnamed: U5.5 (Q), U6.1
unnamed: U5.1 (~R), U5.10 (~S), U6.8
unnamed: U5.9 (Q), U6.2
unnamed: U6.3, U6.4, U6.9
unnamed: U6.10, U6.11
unnamed: U6.5, U7.5 (Q)
unnamed: U8.6, U8.12
unnamed: R7.2, U8.3, U9.3 (C)
unnamed: U9.2 (D), U9.6 (~Q)
unnamed: U8.5, U9.5 (Q)
unnamed: U8.4, U8.9, U8.10, U9.8 (~Q)
Q: J1.7, J2.7, R3.1
SC0: J1.11, J2.11, R1.1
SC1: J1.9, J2.9, R2.1
TPA: J1.14, J2.14, U2.11 (Load)
TPB: J1.16, J2.16, U1.11 (Cp), U3.11 (Cp), U4.11 (Cp), U5.11 (C)
VCC: C1.1, C2.1, C3.1, C4.1, C5.1, C6.1, C7.1, C9.1, C10.1, C11.1, C12.1, C13.1, J1.2, J1.31, J2.2, J2.31, J7.2, RN1.1 (common), U1.20 (VCC), U2.20 (VCC), U3.20 (VCC), U4.20 (VCC), U5.13 (~R), U5.14 (VCC), U6.14 (VCC), U7.14 (VCC), U8.14 (VCC), U9.1 (~R), U9.4 (~S), U9.14 (VCC)
~CLEAR RESET: J6.9, RN1.9 (R8), U7.13 (~R)
~CLEAR SET: J6.8, RN1.8 (R7), U7.10 (~S)
~CLEAR: J1.5, J2.5, R4.1, U7.8 (~Q)
~CLOCK RESET: J6.5, RN1.5 (R4), U9.13 (~R)
~CLOCK SET: J6.4, RN1.4 (R3), U9.10 (~S)
~DMA IN: J1.6, J2.6
~DMA OUT: J1.8, J2.8
~EF1: J1.34, J2.34
~EF2: J1.36, J2.36
~EF3: J1.38, J2.38
~EF4: J1.40, J2.40
~INTERRUPT: J1.10, J2.10
~MRD: J1.13, J2.13
~MWR: J1.12, J2.12
~STEP RESET: J6.3, RN1.3 (R2), U6.12, U6.13
~STEP SET: J6.2, RN1.2 (R1), U5.4 (~S)
~WAIT RESET: J6.7, RN1.7 (R6), U7.1 (~R)
~WAIT SET: J6.6, RN1.6 (R5), U7.4 (~S)
~WAIT: J1.3, J2.3, R5.1, U6.6

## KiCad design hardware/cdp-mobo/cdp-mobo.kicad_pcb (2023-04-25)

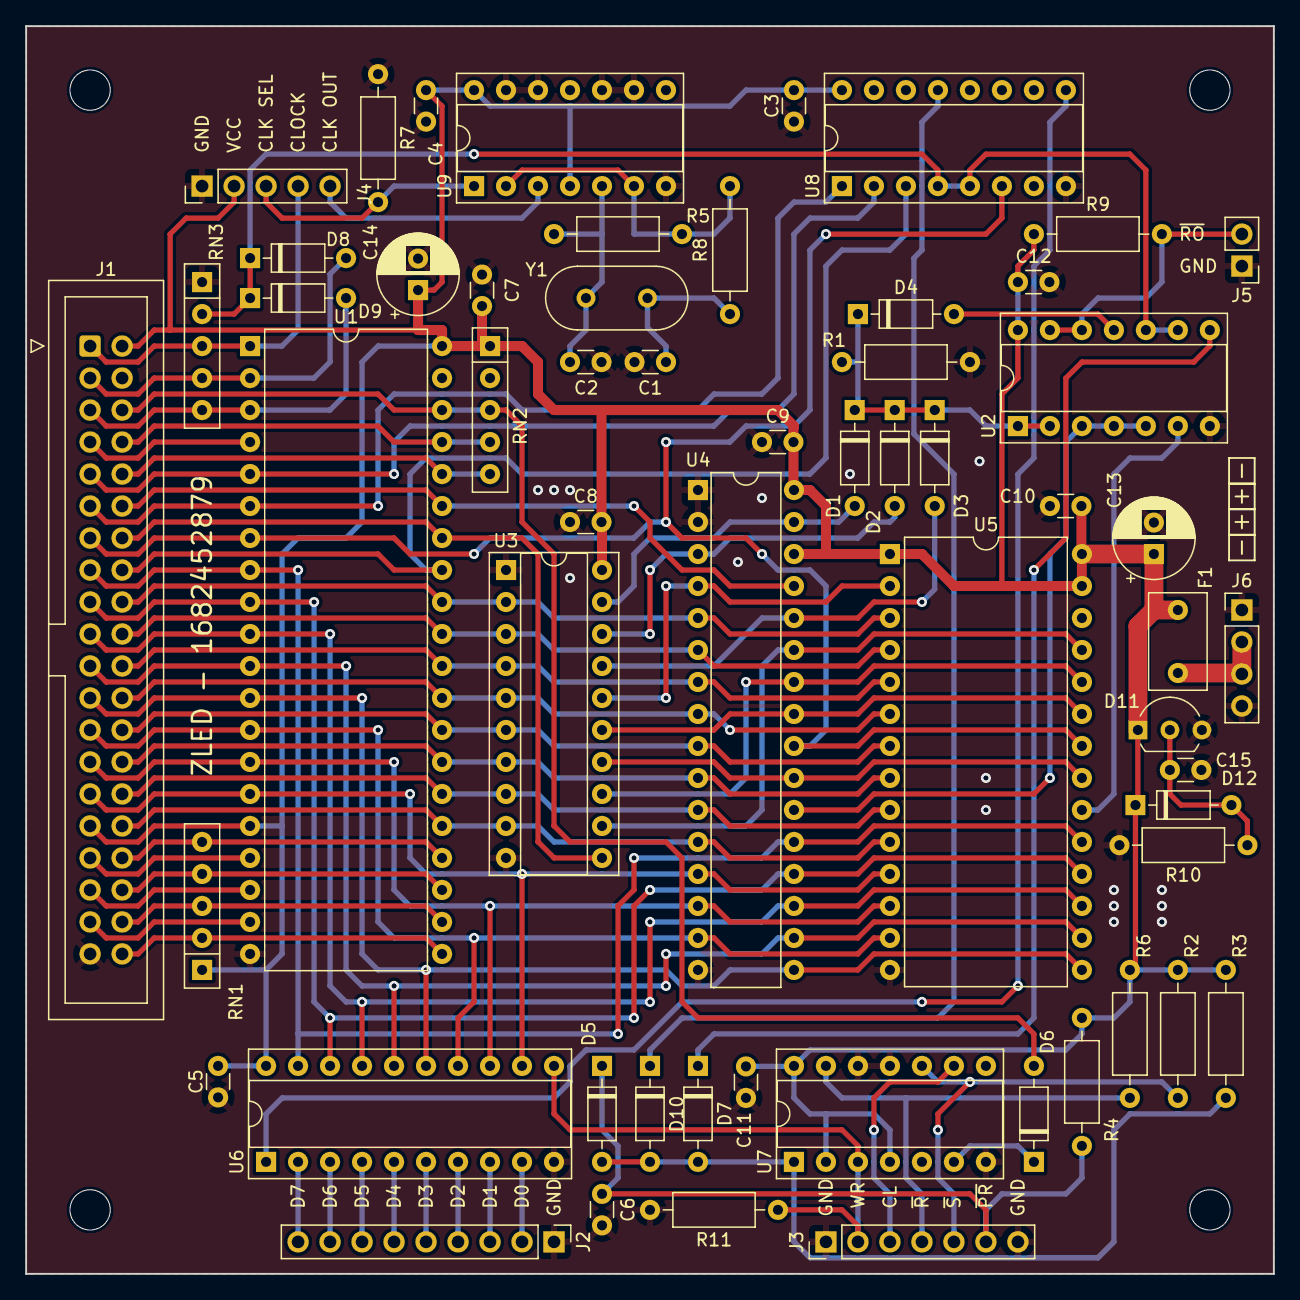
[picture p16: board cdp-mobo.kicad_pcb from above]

Board: 2 copper layers, 99.1 x 99.1 mm, 58 parts (0 on the bottom side), 77 nets.

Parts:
C1, C2: 22pF; C_Disc_D3.0mm_W1.6mm_P2.50mm
C3, C4, C5, C7, C8, C9, C10, C11, C12, C15: 100nF; C_Disc_D3.0mm_W1.6mm_P2.50mm
C6: 220nF; C_Disc_D3.0mm_W1.6mm_P2.50mm
C13, C14: 100uF; CP_Radial_D6.3mm_P2.50mm
D1, D2, D3, D4, D5, D6, D7, D8, D9, D10: 1N4148; D_DO-35_SOD27_P7.62mm_Horizontal
D11: BT149D; TO-92L_Inline_Wide
D12: BZX55C5V1; D_DO-35_SOD27_P7.62mm_Horizontal
F1: 400mA; C_Disc_D7.5mm_W4.4mm_P5.00mm
J1: Conn_02x20_Odd_Even; IDC-Header_2x20_P2.54mm_Vertical
J2: Conn_01x09_Pin; PinHeader_1x09_P2.54mm_Vertical
J3: Conn_01x07_Pin; PinHeader_1x07_P2.54mm_Vertical
J4: Conn_01x05_Pin; PinHeader_1x05_P2.54mm_Vertical
J5: Conn_01x02_Pin; PinHeader_1x02_P2.54mm_Vertical
J6: Conn_01x04_Pin; PinHeader_1x04_P2.54mm_Vertical
R1, R2, R6, R7, R9, R11: 10k; R_Axial_DIN0207_L6.3mm_D2.5mm_P10.16mm_Horizontal
R3, R4: 20k; R_Axial_DIN0207_L6.3mm_D2.5mm_P10.16mm_Horizontal
R5: 1M; R_Axial_DIN0207_L6.3mm_D2.5mm_P10.16mm_Horizontal
R8, R10: 1k; R_Axial_DIN0207_L6.3mm_D2.5mm_P10.16mm_Horizontal
RN1, RN2, RN3: R_Network04; R_Array_SIP5
U1: CDP1802ACE; DIP-40_W15.24mm
U2: 74HC132; DIP-14_W7.62mm_Socket
U3: 74HC573; DIP-20_W7.62mm_Socket
U4: W24512AK-20; DIP-32_W7.62mm
U5: 2764; DIP-28_W15.24mm
U6: 74HC574; DIP-20_W7.62mm_Socket
U7: 74HC74; DIP-14_W7.62mm_Socket
U8: 74HC138; DIP-16_W7.62mm_Socket
U9: 74HC00; DIP-14_W7.62mm_Socket
Y1: 2MHz; Crystal_HC49-U_Vertical

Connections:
/CPU and memories/MA8: U3.12 (Q7), U4.27 (A8), U5.25 (A8)
/CPU and memories/MA9: U3.13 (Q6), U4.26 (A9), U5.24 (A9)
/CPU and memories/MA10: U3.14 (Q5), U4.23 (A10), U5.21 (A10)
/CPU and memories/MA11: U3.15 (Q4), U4.25 (A11), U5.23 (A11)
/CPU and memories/MA12: U3.16 (Q3), U4.4 (A12), U5.2 (A12)
/CPU and memories/MA13: D3.2 (A), U3.17 (Q2), U4.28 (A13)
/CPU and memories/MA14: D2.2 (A), U3.18 (Q1), U4.3 (A14)
/CPU and memories/MA15: D1.2 (A), U3.19 (Q0), U4.31 (A15)
CLK OUT: J4.5, U9.3
CLK SEL: J4.3, R7.2, U9.1
CLOCK: J1.1, J4.4, RN3.3 (R2), U1.1 (CLOCK)
D0: J1.29, U1.15 (BUS0), U4.13 (D0), U5.11 (D0), U6.12 (Q7)
D1: J1.27, U1.14 (BUS1), U4.14 (D1), U5.12 (D1), U6.13 (Q6)
D2: J1.25, U1.13 (BUS2), U4.15 (D2), U5.13 (D2), U6.14 (Q5)
D3: J1.23, U1.12 (BUS3), U4.17 (D3), U5.15 (D3), U6.15 (Q4)
D4: J1.21, U1.11 (BUS4), U4.18 (D4), U5.16 (D4), U6.16 (Q3)
D5: J1.19, U1.10 (BUS5), U4.19 (D5), U5.17 (D5), U6.17 (Q2)
D6: J1.17, U1.9 (BUS6), U4.20 (D6), U5.18 (D6), U6.18 (Q1)
D7: J1.15, U1.8 (BUS7), U4.21 (D7), U5.19 (D7), U6.19 (Q0)
DIN0: J2.2, U6.9 (D7)
DIN1: J2.3, U6.8 (D6)
DIN2: J2.4, U6.7 (D5)
DIN3: J2.5, U6.6 (D4)
DIN4: J2.6, U6.5 (D3)
DIN5: J2.7, U6.4 (D2)
DIN6: J2.8, U6.3 (D1)
DIN7: J2.9, U6.2 (D0)
DMA WRITE: J3.2, R11.1, U6.11 (Cp), U7.3 (C)
GND: C1.2, C2.2, C3.2, C4.2, C5.2, C6.2, C7.2, C8.1, C9.1, C10.1, C11.1, C12.2, C13.2, C14.2, C15.2, D11.3 (K), J1.4, J1.39, J2.1, J3.1, J3.7, J4.1, J5.1, J6.1, J6.4, R1.2, R7.1, R10.2, R11.2, RN3.1 (common), U1.20 (VSS), U2.7 (GND), U3.1 (OE), U3.10 (GND), U4.1 (NC), U4.2 (NC), U4.16 (VSS), U5.14 (GND), U6.10 (GND), U7.7 (GND), U7.11 (C), U7.12 (D), U8.8 (GND), U9.7 (GND), U9.9, U9.10, U9.12, U9.13
MA0: J1.32, U1.25 (MA0), U3.9 (D7), U4.12 (A0), U5.10 (A0)
MA1: J1.30, U1.26 (MA1), U3.8 (D6), U4.11 (A1), U5.9 (A1)
MA2: J1.28, U1.27 (MA2), U3.7 (D5), U4.10 (A2), U5.8 (A2)
MA3: J1.26, U1.28 (MA3), U3.6 (D4), U4.9 (A3), U5.7 (A3)
MA4: J1.24, U1.29 (MA4), U3.5 (D3), U4.8 (A4), U5.6 (A4)
MA5: J1.22, U1.30 (MA5), U3.4 (D2), U4.7 (A5), U5.5 (A5)
MA6: J1.20, U1.31 (MA6), U3.3 (D1), U4.6 (A6), U5.4 (A6)
MA7: J1.18, U1.32 (MA7), U3.2 (D0), U4.5 (A7), U5.3 (A7)
N0: J1.37, U1.19 (N0)
N1: J1.35, U1.18 (N1)
N2: J1.33, U1.17 (N2)
unnamed: C1.1, R8.1, Y1.2
unnamed: C2.1, R5.2, U9.5, Y1.1
unnamed: D1.1 (K), D2.1 (K), D3.1 (K), D4.1 (K), R1.1, U2.1, U2.2
unnamed: D4.2 (A), U2.11
unnamed: D6.1 (K), U7.6 (~Q)
unnamed: D7.1 (K), U2.8
unnamed: D5.2 (A), D7.2 (A), D10.2 (A), R3.2, U7.1 (~R)
unnamed: D10.1 (K), U8.13 (O2)
unnamed: C15.1, D11.2 (G), D12.2 (A), R10.1
unnamed: F1.2, J6.2, J6.3
unnamed: R5.1, R8.2, U9.2, U9.6
unnamed: U6.1 (OE), U8.9 (O6)
Q: J1.7, U1.4 (Q)
SC0: J1.11, U1.6 (SC0), U8.1 (A0)
SC1: J1.9, U1.5 (SC1), U8.2 (A1)
TPA: J1.14, U1.34 (TPA), U3.11 (Load)
TPB: J1.16, U1.33 (TPB), U8.3 (A2)
VCC: C3.1, C4.1, C5.1, C7.1, C8.2, C9.2, C10.2, C11.2, C12.1, C13.1, C14.1, D11.1 (A), D12.1 (K), F1.1, J1.2, J1.31, J4.2, R2.1, R3.1, R4.1, R6.1, R9.1, RN1.1 (common), RN2.1 (common), U1.16 (VCC), U1.40 (VDD), U2.14 (VCC), U3.20 (VCC), U4.30 (CS2), U4.32 (VDD), U5.1 (VPP), U5.27 (~PGM), U5.28 (VCC), U6.20 (VCC), U7.2 (D), U7.4 (~S), U7.14 (VCC), U8.16 (VCC), U9.4, U9.14 (VCC)
WRITE CLK: J3.3, U7.9 (Q)
~CLEAR: D9.2 (A), J1.5, RN3.5 (R4), U1.3 (~CLEAR)
~DMA IN: D6.2 (A), J1.6, RN2.3 (R2), U1.38 (~DMA_IN)
~DMA OUT: J1.8, RN2.4 (R3), U1.37 (~DMA_OUT)
~EF1: J1.34, RN1.5 (R4), U1.24 (~EF1)
~EF2: J1.36, RN1.4 (R3), U1.23 (~EF2)
~EF3: J1.38, RN1.3 (R2), U1.22 (~EF3)
~EF4: J1.40, RN1.2 (R1), U1.21 (~EF4)
~INTERRUPT: J1.10, RN2.5 (R4), U1.36 (~INTERRUPT)
~LOAD EN: D8.1 (K), D9.1 (K), RN3.2 (R1), U2.9, U2.10, U8.4 (E1), U8.5 (E2)
~MRD: J1.13, U1.7 (~MRD), U4.24 (~OE), U5.22 (~OE), U8.6 (E3)
~MWR: J1.12, U1.35 (~MWR), U4.29 (~WE)
~PROTECT: C6.1, D5.1 (K), J3.6, R4.2
~RAM ONLY: J5.2, R9.2, U2.12, U2.13
~RAM_CS: U2.3, U2.4, U2.5, U4.22 (~CS1)
~ROM_CS: U2.6, U5.20 (~CE)
~WAIT: D8.2 (A), J1.3, RN3.4 (R3), U1.2 (~WAIT)
~WRITE RESET: J3.4, R6.2, U7.13 (~R)
~WRITE SET: J3.5, R2.2, U7.10 (~S)

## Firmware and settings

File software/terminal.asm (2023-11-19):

DMA_REG EQU 0
INTP_REG EQU 1
INTX_REG EQU 2
PC_REG EQU 3
R4 EQU 4
R5 EQU 5
R6 EQU 6
R7 EQU 7
R8 EQU 8
R9 EQU 9
R10 EQU 10
R11 EQU 11
R12 EQU 12
CALL_REG EQU 13
FCALL_REG EQU 14
RETURN EQU 14
STACK_REG EQU 15

STACK_ADDRESS EQU 0FFFFh
DMA_ADDRESS EQU 03000h

INPUT_BUFF EQU 02000h

VARLIST_COUNT EQU 02100h
VARLIST_FIRSTNODE EQU 02102h
VARLIST_LASTNODE EQU 02104h

HEAP_LASTADDRESS EQU 02106h
HEAP_START EQU 02110h
HEAP_END EQU 0FC00h


    org 00h

START
    dis
    idl
    
    seq     ;set Q output to high
    
    ldi STACK_ADDRESS.0 ;setup the STACK pointer
    plo STACK_REG
    ldi STACK_ADDRESS.1
    phi STACK_REG
    
    ldi FCALL.1         ;setup FCALL
    phi FCALL_REG
    
    ldi DMA_INIT.0      ;switch PC to R3 and init DMA
    plo PC_REG
    ldi DMA_INIT.1
    phi PC_REG
    
    sep PC_REG
    
DMA_INIT
    ldi DMA_ADDRESS.0   ;setup DMA address
    plo DMA_REG
    ldi DMA_ADDRESS.1
    phi DMA_REG
    
    lbr MAIN_PROGRAM
    
;-FUNCTION CALL HELPER-------------------------
;-WHERE TO JUMP-(CALL_REG)---------------------
    org 0100h
    
FCALL
    sex STACK_REG   ;set STACK as X register
    ghi PC_REG      ;saving the PC value to stack
    stxd
    glo PC_REG
    stxd
    
    glo CALL_REG    ;put the new address in the PC
    plo PC_REG
    ghi CALL_REG
    phi PC_REG
    sep PC_REG      ;jumping to PC
    
FRETURN
    inc STACK_REG   ;increment the STACK register
    sex STACK_REG   ;set STACK as X register
    ldxa            ;restoring PC from STACK
    plo PC_REG
    ldx
    phi PC_REG
    sep PC_REG      ;jumping to PC
    br FRETURN
;----------------------------------------------

;-SERIAL SEND BYTE-----------------------------
;-DATA-R4.1------------------------------------
SERIAL_SEND_START
    ghi R4      ;R4 high is the data, load it into the D reg
    xri 0FFh    ;invert it
    phi R4      ;put it back
    ldi 085h    ;load 0x85 to the D reg
    shl         ;shift it left so we get 0x0A and set the flag bit
    plo R4      ;put the 0x10 to R4 low, this will be our bit counter

SERIAL_SEND_BIT
    lsnf        ;24 - long skip if the flag is not set
    req         ;16 - reset Q if the flag is set
    lskp        ;24
    seq         ;16 - set Q if the flag is not set
    nop         ;24
    
    dec R4      ;16 - decrement R4, this will only affect the R4 lower 8bit
    glo R4      ;16
    lsnz        ;24 - if R4 lower is not 0 then long skip
    sep RETURN  ;--
    nop         ;--
    ghi R4      ;16 - get R4 high
    shr         ;16 - shift it right to get LSB in the flag
    phi R4      ;16 - put it back
    nop         ;24
    nop         ;24
    nop         ;24
    br SERIAL_SEND_BIT ;16
;----------------------------------------------

;-SERIAL READ BYTE-----------------------------
;-RETURN R5.1----------------------------------
SERIAL_READ_START
    ldi 00h     ;set input data register to 0
    plo R5
    phi R5
    
SERIAL_WAIT_START
    bn1 SERIAL_WAIT_START ;16 - loop until EF1 goes low
    nop         ;24
    nop         ;24
    nop         ;24
    nop         ;24
    ori 00h     ;16 - do nothing for 16 clock cycles

SERIAL_SAMPLE_BIT
    b1 SERIAL_NULL_BIT  ;16 - checking the EF1
    ori 080h            ;16 - if EF1 is high then set MSB to 1 in D register
    br SERIAL_SAVE_BIT  ;16

SERIAL_NULL_BIT
    ori 00h         ;16 - of EF1 is low we do nothing
    ori 00h         ;16

SERIAL_SAVE_BIT
    phi R5          ;16 - put D in R5 high
    inc R5          ;16 - increment R5, this will only affect R5 low 8bit
    glo R5          ;16 - get R5 low to D register
    xri 09h         ;16 - D = D ^ 0x09
    lsnz            ;24 
    sep RETURN      ;--
    nop             ;--
    ghi R5          ;16 - get R5 high
    shr             ;16 - shift it righ
    nop             ;24
    nop             ;24
    nop             ;24
    br SERIAL_SAMPLE_BIT ;16
;----------------------------------------------

;-PRINT----------------------------------------
;-FIRST CHAR-R6--------------------------------
PRINT
    sex R6          ;set X register to R6
    ldxa            ;load data to D and increment R6
    lsnz            ;if it is not zero then long skip
    sep RETURN
    nop
    
    phi R4          ;put D register to R4 to send it
    
    ldi SERIAL_SEND_START.0     ;prepare to call SERIAL_SEND
    plo CALL_REG
    ldi SERIAL_SEND_START.1
    phi CALL_REG
    
    ldi FCALL.0
    plo FCALL_REG
    sep FCALL_REG   ;call SERIAL_SEND
    br PRINT
;----------------------------------------------

BACKSPACE_ACTION
    db 8, 32, 8, 0
;-READ LINE------------------------------------
;-WHERE TO READ-R7-----------------------------
;-R8.1-Character counter-------------------------
READLINE
    ldi 0
    plo R8
    
READLINE_LOOP
    ldi SERIAL_READ_START.0     ;prepare calling SERIAL_READ
    plo CALL_REG
    ldi SERIAL_READ_START.1
    phi CALL_REG
    
    ldi FCALL.0
    plo FCALL_REG
    sep FCALL_REG       ;call SERIAL_READ
    
    ghi R5              ;get the result of SERIAL_READ
    xri 13              ;check if it is 13 (ENTER KEY)
    bnz READLINE_BACKSPACE      ;if not jump to READLINE_BACKSPACE
    
END_LINE
    ldi 00h             ;put 0 to the endof the string
    str R7
    
    ldi NEW_LINE.0      ;load the address of CRLF string
    plo R6
    ldi NEW_LINE.1
    phi R6
    
    ldi PRINT.0         ;prepare to call PRINT
    plo CALL_REG
    ldi PRINT.1
    phi CALL_REG
    
    ldi FCALL.0
    plo FCALL_REG
    sep FCALL_REG       ;call PRINT
    
    sep RETURN          ;RETURN from READLINE
    
READLINE_BACKSPACE
    ghi R5              ;get the result of SERIAL_READ
    xri 127             ;check if it is 127 (DEL)
    bnz STORE_CHAR      ;if not jump to STORE_CHAR
    
    glo R8
    bz READLINE_LOOP
    
    ldi BACKSPACE_ACTION.0      ;load the address of the backspace action
    plo R6
    ldi BACKSPACE_ACTION.1
    phi R6
    
    ldi PRINT.0                 ;prepare to call PRINT
    plo CALL_REG
    ldi PRINT.1
    phi CALL_REG
    
    ldi FCALL.0
    plo FCALL_REG
    sep FCALL_REG               ;call PRINT
    
    dec R7
    dec R8
    
    br READLINE_LOOP
    
STORE_CHAR
    glo R8
    xri 0FFh
    bz READLINE_LOOP
    
    ghi R5              ;get the result of the SERIAL_READ again
    str R7              ;store it where R7 pointing
    inc R7              ;increment R7
    inc R8
    
    phi R4              ;load the result to R4 to Echo it back
    
    ldi SERIAL_SEND_START.0     ;prepare to call SERIAL_SEND
    plo CALL_REG
    ldi SERIAL_SEND_START.1
    phi CALL_REG
    
    ldi FCALL.0
    plo FCALL_REG
    sep FCALL_REG       ;call SERIAL_SEND
    br READLINE_LOOP
;----------------------------------------------

;-STR COMPARATOR-------------------------------
;-R8 stringA-R9 stringB------------------------
;-RETURN R10.0---------------------------------
STR_COMPARATOR
    ldi 0           ;R10 low is the result, set it to 0
    plo R10
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

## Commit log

2023-04-25 Upload files.
    [cdp-connectors.kicad_sch, cdp-cpu.kicad_sch, cdp-dmaif.kicad_sch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]
2023-05-29 Minor changes in component values, and added a the IO module.
    [cdp-connectors.kicad_sch, cdp-cpu.kicad_sch, cdp-io.kicad_pcb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]
2023-05-29 Added the controller page, and two decoders are placed in it. Moved some files, and added the gitignore file.
    [cdp-connectors.kicad_sch, cdp-controller.kicad_sch, cdp-io.kicad_pcb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]
2023-06-04 The controller is finished. U7 is changed to a hex inverter.
    [cdp-controller.kicad_sch, cdp-io.kicad_pcb, cdp-porta.kicad_sch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]
2023-06-04 Changed the layout a bit, started to work on the PCB.
    [cdp-controller.kicad_sch, cdp-io.kicad_pcb, cdp-porta.kicad_sch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]
2023-06-17 Changed the schematic a bit.
    [cdp-controller.kicad_sch, cdp-io.kicad_pcb, cdp-porta.kicad_sch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]
2023-07-02 A really small progress.
    [cdp-connectors.kicad_sch, cdp-controller.kicad_sch, cdp-io.kicad_pcb]
2023-07-04 Renamed a few net, and changed the schematic a bit. The PCB is ready!
    [cdp-connectors.kicad_sch, cdp-controller.kicad_sch, cdp-io.kicad_pcb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]
2023-07-06 The final version of the IO board. Gerber files added.
    [cdp-connectors.kicad_sch, cdp-controller.kicad_sch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]
2023-07-06 IC names fixed on the led driver schematic, on the PCB the MA8-MA15 labels were misaligned that is also fixed. Updated the gerber files.
    [cdp-flipflops.kicad_sch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]
2023-07-06 IC names fixed. PCB is updated. Gerber files are still ok.
    [cdp-controller.kicad_sch, cdp-io.kicad_pcb, cdp-porta.kicad_sch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]
2023-07-06 cdpcmobo ZIP file is removed from the gerber folder. Added PDF schematic.
2023-08-13 Added backspace handling, and 255 character limit to the readline function, and fixed some branches.
    [terminal.asm]
2023-10-10 Fixed the parenthesis handling in the interpreter.
    [terminal.asm]
2023-10-12 mem_view command now accepts two parameter, fixed some bugs.
    [terminal.asm]
2023-11-05 mem_alloc size equality test fixed.
    [terminal.asm]
2023-11-05 Fixed the addressing in the LET_STATEMENT_FREENODE.
    [terminal.asm]
2023-11-10 Minor fix in the READ_VAR.
    [terminal.asm]
